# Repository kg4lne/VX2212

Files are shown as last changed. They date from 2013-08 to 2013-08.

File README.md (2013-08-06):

VX2212 EPROM Emulator
=====================

This archive contains all the CAD and firmware files necessary to build the VX2212 EPROM emulator for vintage GE Phoenix VHF/UHF commercial radios. For more information, please visit the website at http://www.rtzaudio.com/kg4lne.

This package includes all PCB CAD files in Cadsoft Eagle v6.4.0 format. The source code and firmware HEX file are included also.

The BOM files are located in the BOM subdirectory and also includes an order upload file for Digikey to preload all parts for ordering with the Digikey BOM manager. 

Hope you enjoy the project!

KG4LNE

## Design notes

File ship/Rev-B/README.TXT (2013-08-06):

These files were generated in RS274-X format (embedded apertures)
using CadSoft Eagle 5.11.0 (Win2K):

VX2212-REV-B		03/17/2011

VX2212-REV-B.PDF	Gerber Data - Fabrication drawing in Adobe PDF format
VX2212-REV-B.CMP	Gerber Data - Component side
VX2212-REV-B.SOL	Gerber Data - Solder side
VX2212-REV-B.PLC	Gerber Data - Silk screen component side
VX2212-REV-B.PLS	Gerber Data - Silk screen bottom side
VX2212-REV-B.STC	Gerber Data - Solder stop mask component side
VX2212-REV-B.STS	Gerber Data - Solder stop mask solder side
VX2212-REV-B.DRL	Drill rack file
VX2212-REV-B.DRI	Drill info file
VX2212-REV-B.DRD	Drill data for NC drill station
VX2212-REV-B.GPI	Gerber photoplotter info file

NOTE: ALL LAYERS GENERATED WITH MIRRORING OFF!

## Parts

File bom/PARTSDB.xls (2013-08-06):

Mfg Part Num | Mfg Name | VID | Vendor Part Num | Description
DNP | DO NOT PLACE | (DNP) | DNP | DO NOT PLACE
CC0603KRX7R9BB104 | Yaego | DK | 311-1344-1-ND | CAP CERAMIC .1UF 50V X7R 0603
CC0603JRNPO9BN220 | Yaego | DK | 311-1062-1-ND | CAP CERAMIC 22PF 50V 0603 SMD
T491B106K016AT | Kemet | DK | T491B106K016AT | CAP TANTALUM 10UF 16V 10% SMD 3528
ERJ-3EKF47R5V | Panasonic | DK | P47.5HCT-ND | RES 47.5 OHM 1/10W 1% 0603 SMD
ERJ-3EKF1000V | Panasonic | DK | P100HCT-ND | RES 100 OHM 1/10W 1% 0603 SMD
ERJ-3EKF4750V | Panasonic | DK | P475HCT-ND | RES 475 OHM 1/10W 1% 0603 SMD
ERJ-3EKF1002V | Panasonic | DK | P10.0KHCT-ND | RES 10.0K OHM 1/10W 1% 0603 SMD
ERJ-3EKF1003V | Panasonic | DK | P100KHCT-ND | RES 100K OHM 1/10W 1% 0603 SMD
742C083470JTR | CTS Resistor Products | DK | 742C083470JPCT-ND | RES ARRAY 47 OHM 8TERM 4RES SMD
MAX3223IPWR | Texas Instruments | DK | 296-13092-1-ND | IC DRVR/RCVR MLTCH RS232 20TSSOP
ATMEGA8-16AU | Atmel Corp | DK | ATMEGA8-16AU-ND | IC AVR MCU 8K 16MHZ IND 32-TQFP
MMBT3904LT1 | Infineon Technologies | DK | MMBT3904LT1INCT-ND | TRANSISTOR SWITCHING NPN SOT-23
BAV16W-7-F | Diodes Inc | DK | BAV16W-FDICT-ND | DIODE SWITCH 75V 400MW SOD123
MBR140SFT1G | ON Semiconductor | DK | MBR140SFT1GOSCT-ND | DIODE SCHOTTKY 40V 1A SOD123FL
MMSD4148 | Fairchild Semiconductor | DK | MMSD4148CT-ND | DIODE SML SIG 100V 0.2A SOD123
LTST-C190GKT | Lite-On Inc | DK | 160-1183-1-ND | LED GREEN CLEAR 0603 SMD
MCR03EZPJ000 | Rohm Semiconductor | DK | RHM0.0GCT-ND | RES 100K OHM 1/10W 1% 0603 SMD
801-93-050-10-001000 | Mill-Max Manufacturing | DK | ED7150-ND | SIP SOCKET 50 POS STRAIGHT PCB
ECS-147.4-18-9X | ECS Inc | DK | XC1382-ND | CRYSTAL 14.7456MHZ 18PF CYLINDR
961206-6404-AR | 3M | DK | 3M9459-ND | CONN HEADER VERT DUAL 6POS GOLD
961102-6404-AR | 3M | DK | 3M9447-ND | CONN HEADER VERT SGL 2POS GOLD
969102-0000-DA | 3M | DK | 3M9580-ND | SHUNT JUMPER .1" BLACK GOLD

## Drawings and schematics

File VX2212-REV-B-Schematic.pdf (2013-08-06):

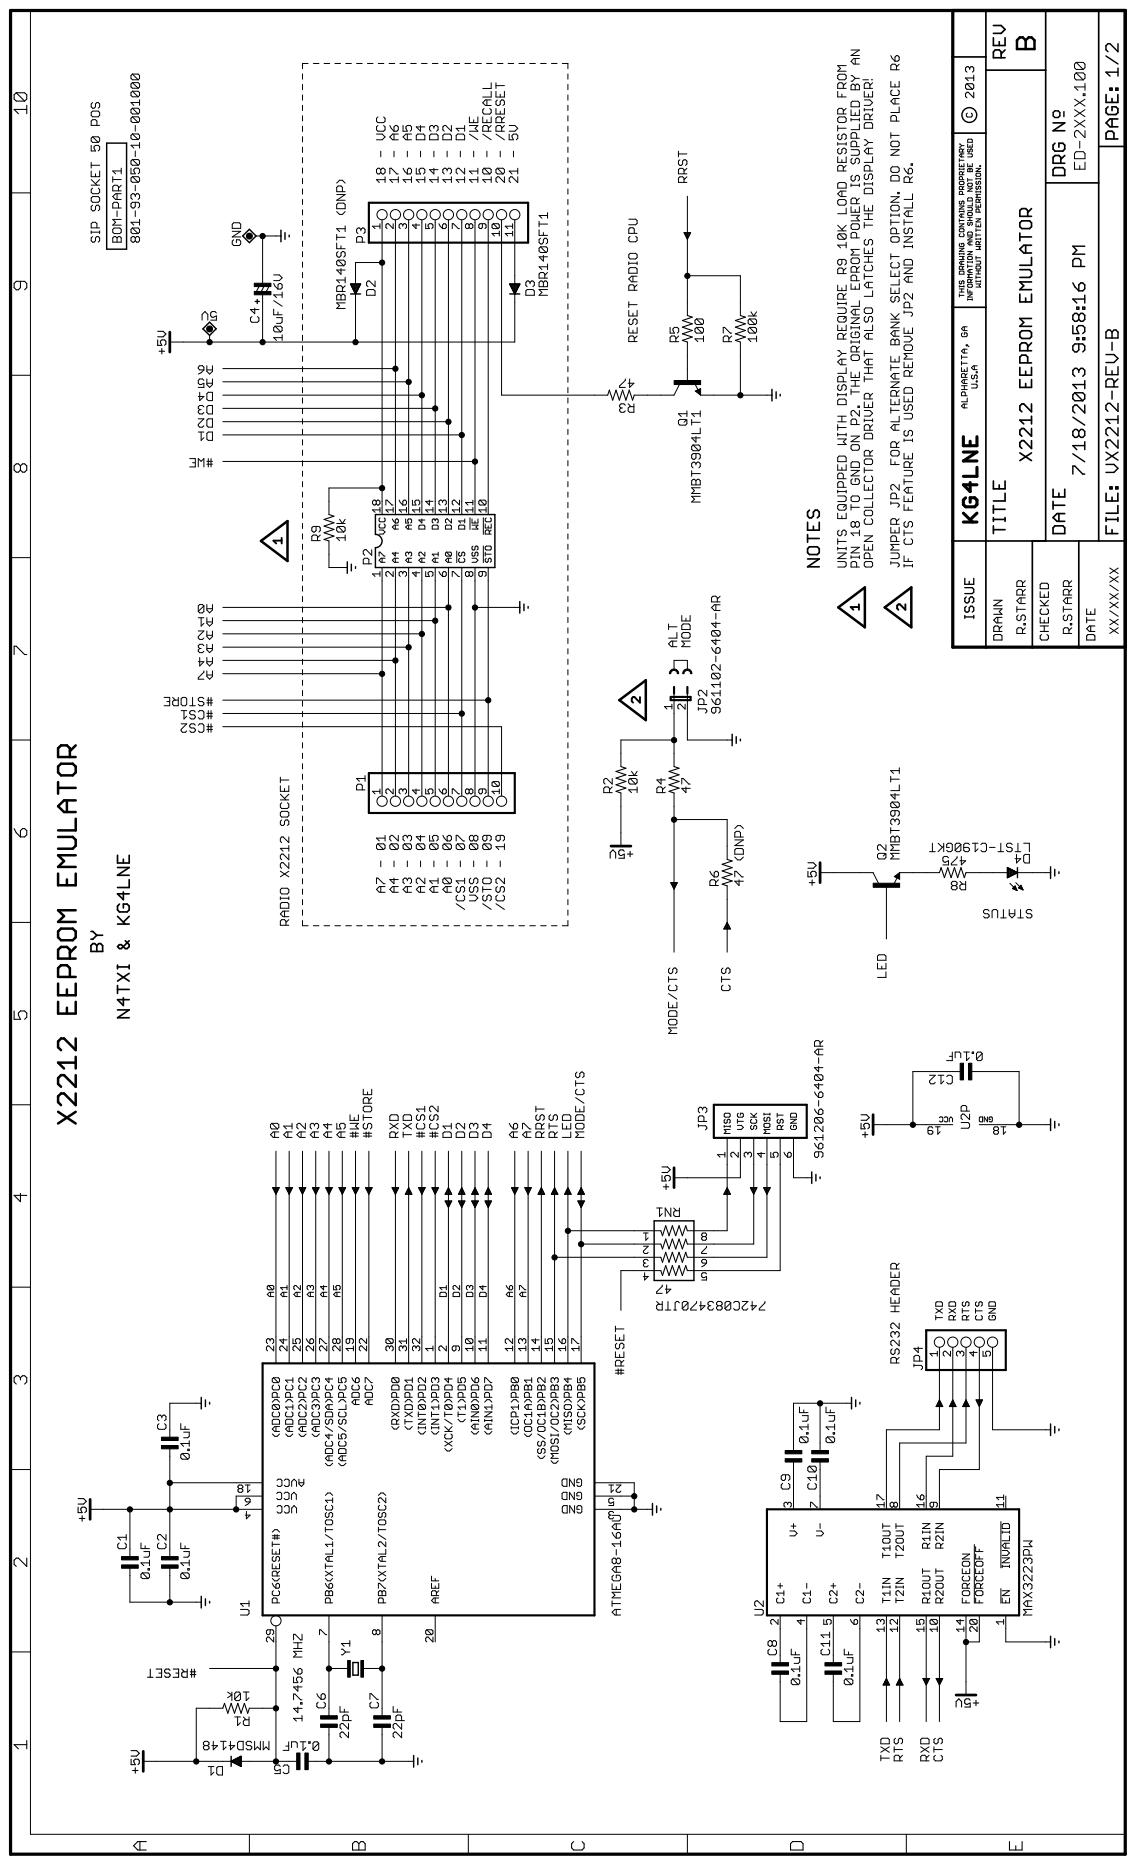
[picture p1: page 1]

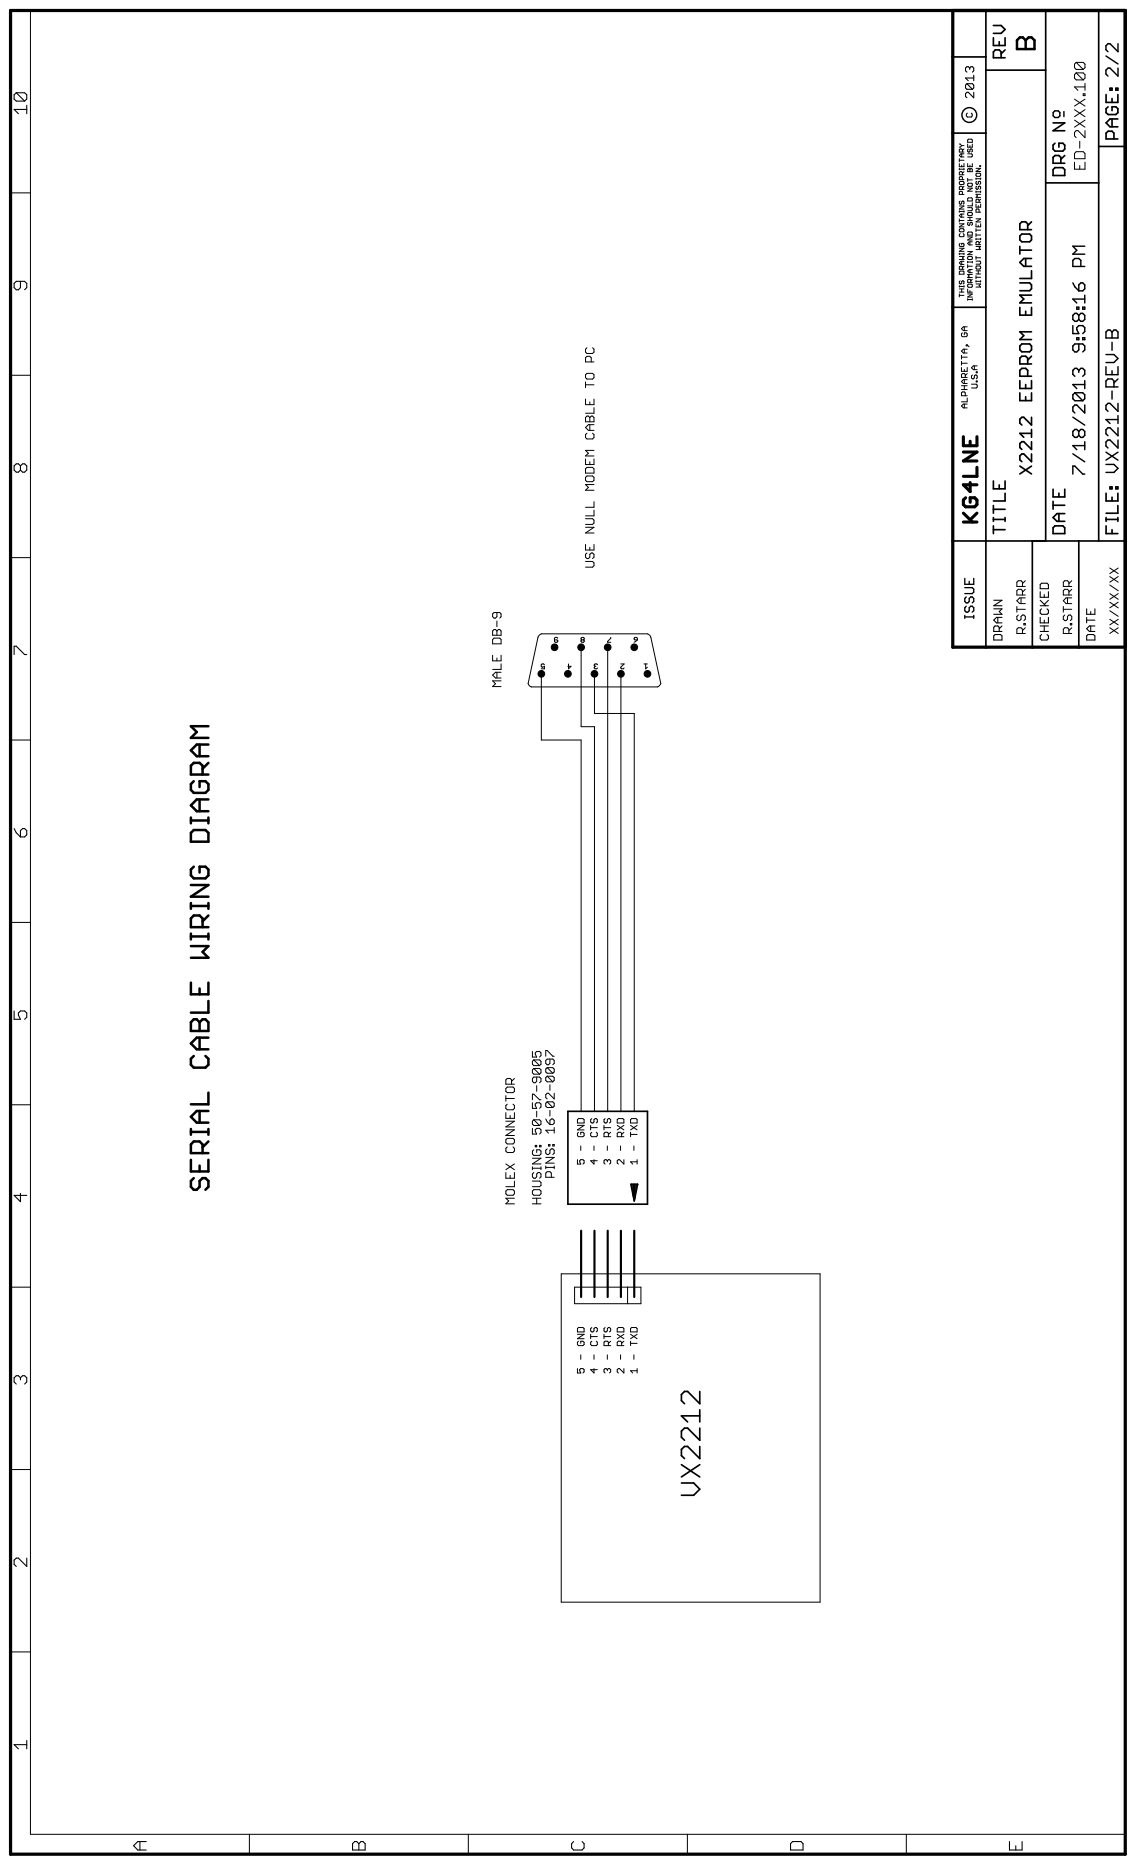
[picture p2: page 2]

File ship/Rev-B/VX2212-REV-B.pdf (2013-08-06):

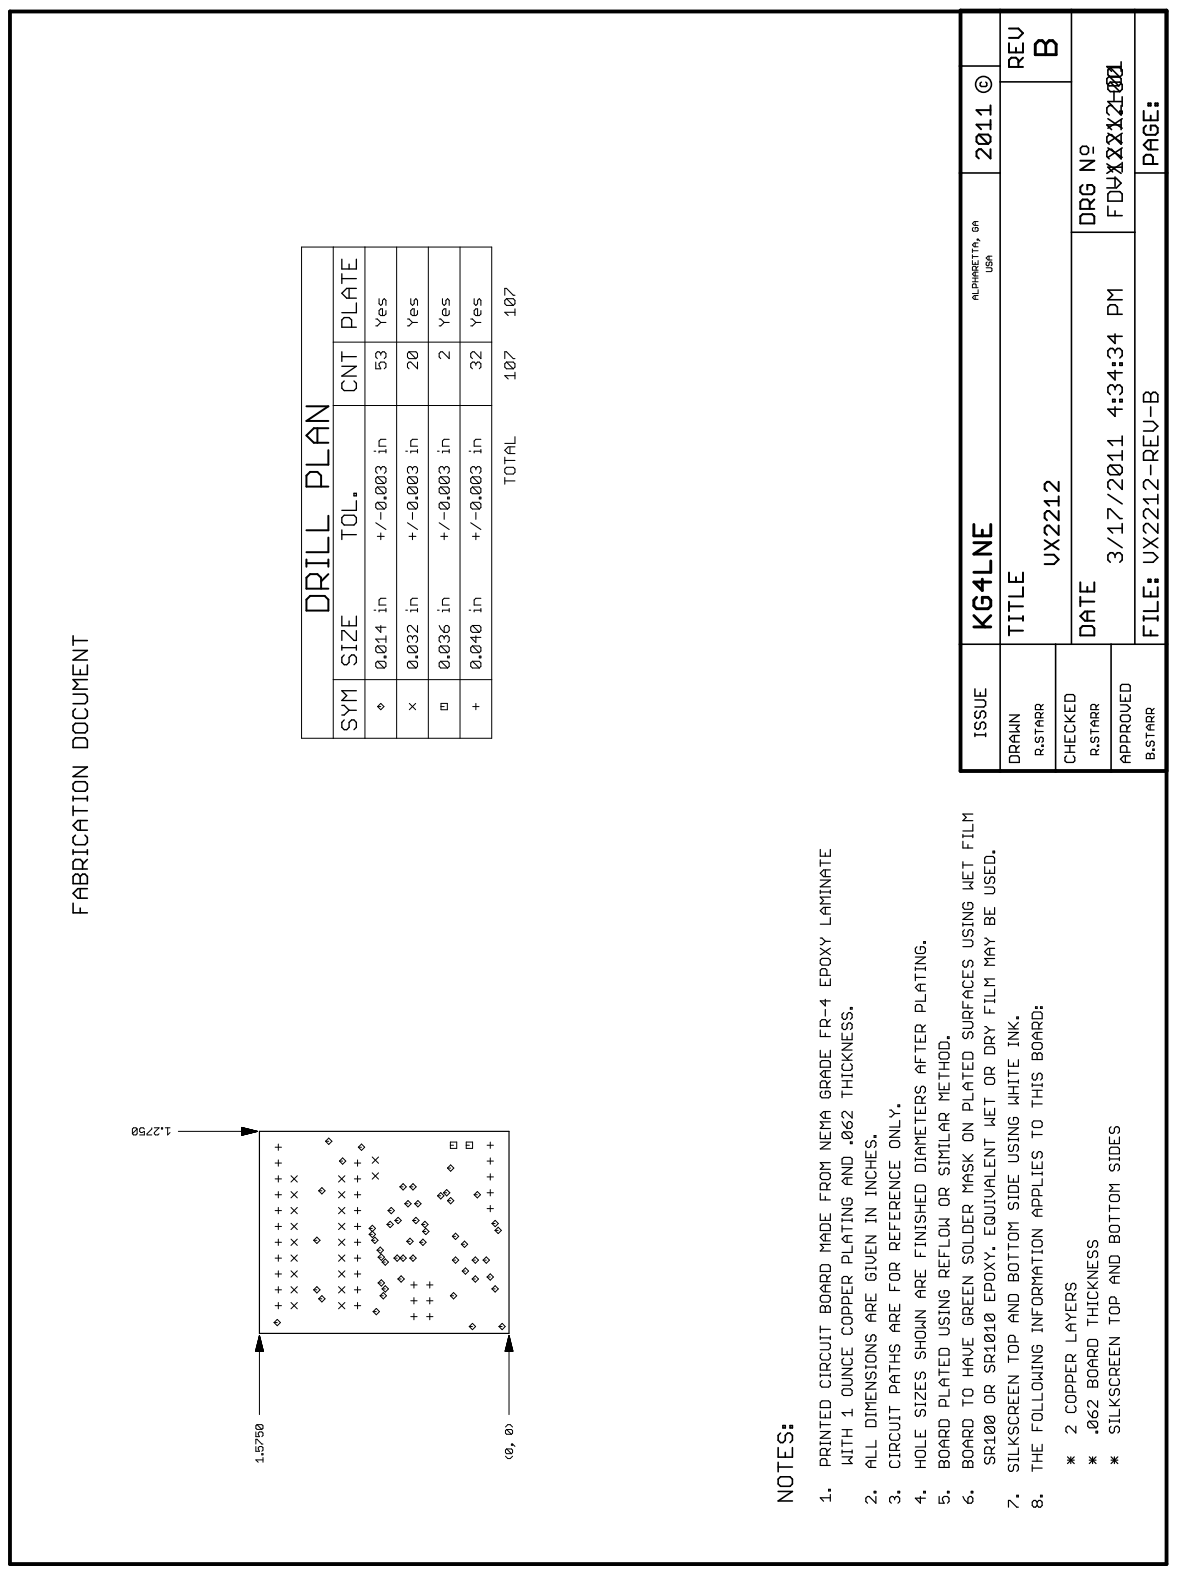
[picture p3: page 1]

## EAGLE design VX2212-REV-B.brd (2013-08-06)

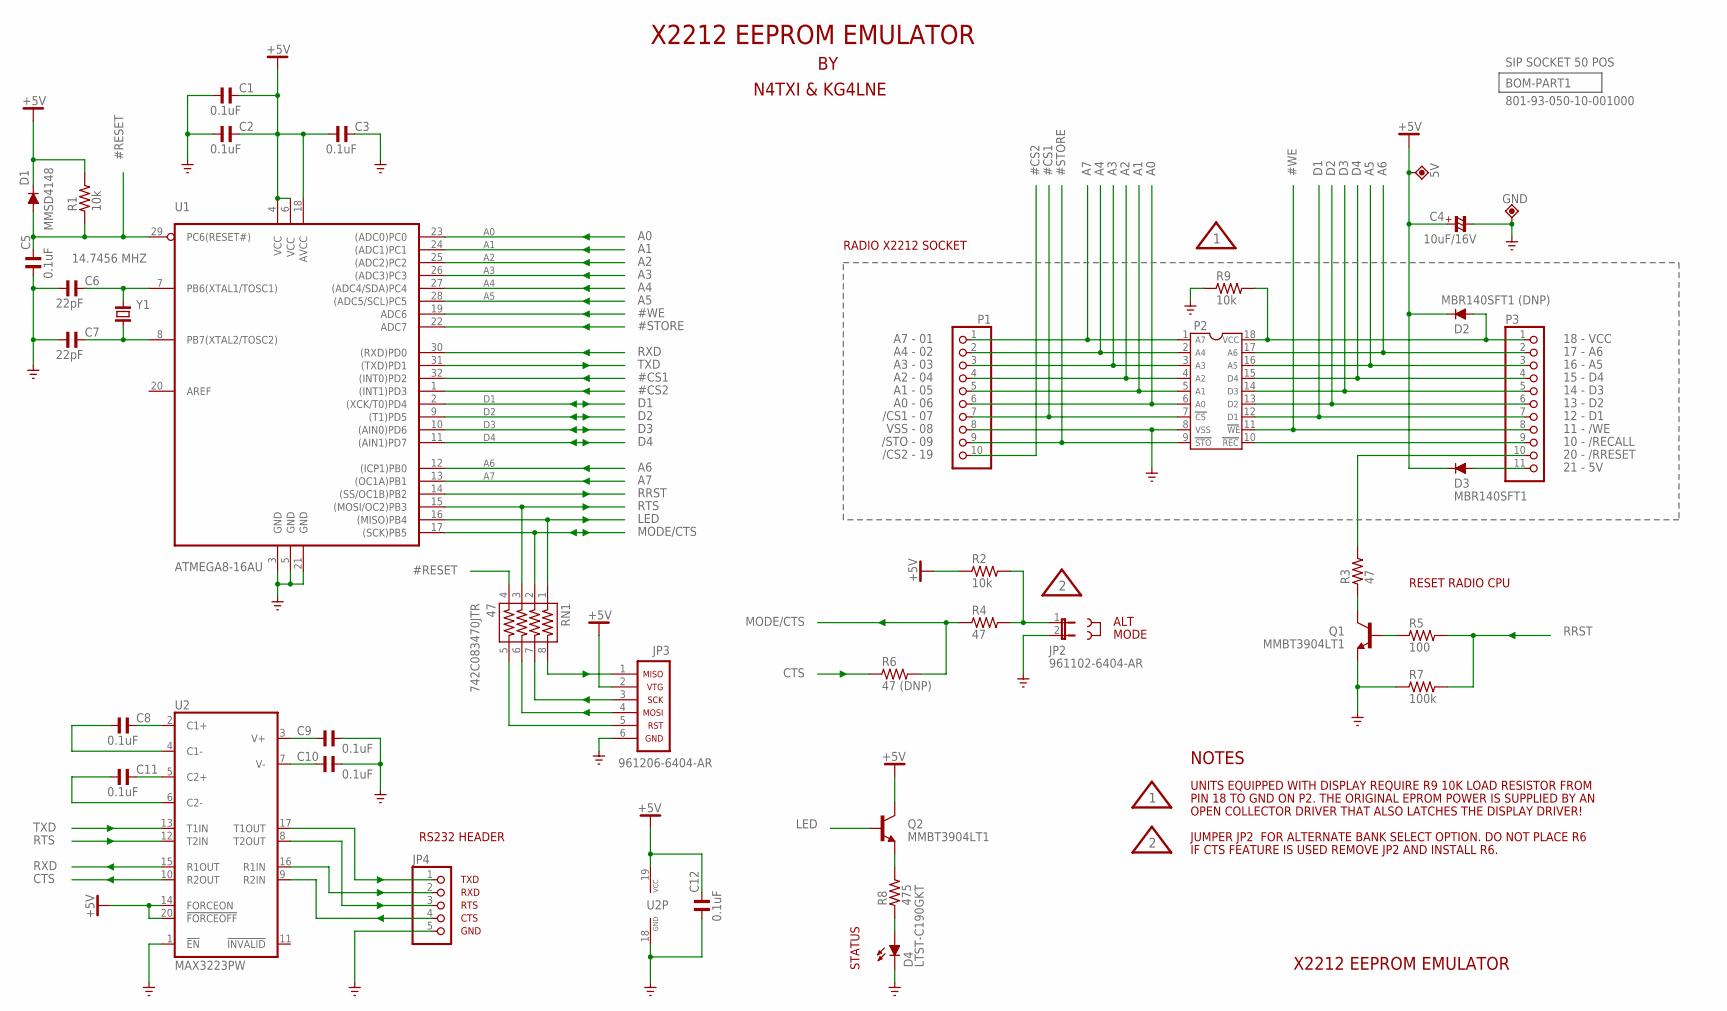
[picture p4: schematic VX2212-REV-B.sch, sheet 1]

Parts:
5V: TPP-SMD-08SN; SMD-08SN
C1, C2, C3, C5, C8, C9, C10, C11, C12: 0.1uF; C0603; PARTNO CC0603KRX7R9BB104
C4: 10uF/16V; C3528/T; PARTNO T491B106K016AT
C6, C7: 22pF; C0603; PARTNO CC0603JRNPO9BN220
D1: MMSD4148; SOD123; PARTNO MMSD4148
D2: MBR140SFT1 (DNP); SOD123LF; PARTNO DNP
D3: MBR140SFT1; SOD123LF; PARTNO MBR140SFT1G
D4: LTST-C190GKT; CHIPLED_0603; PARTNO LTST-C190GKT
GND: TPP-SMD-08SN; SMD-08SN
JP2: 961102-6404-AR; JP1; PARTNO 961102-6404-AR
JP3: 961206-6404-AR; AVR-ISP-6; PARTNO 961206-6404-AR
JP4: PINHD-1X5; 1X05
P1: PINHD-1X10; 1X10
P2: DIL18-NS
P3: PINHD-1X11; 1X11
Q1, Q2: MMBT3904LT1; SOT23-BEC; PARTNO MMBT3904LT1
R1, R2, R9: 10k; R0603; PARTNO ERJ-3EKF1002V
R3, R4: 47; R0603; PARTNO ERJ-3EKF47R5V
R5: 100; R0603; PARTNO ERJ-3EKF1000V
R6: 47 (DNP); R0603; PARTNO DNP
R7: 100k; R0603; PARTNO ERJ-3EKF1003V
R8: 475; R0603; PARTNO ERJ-3EKF4750V
RN1: 47; 742-8; PARTNO 742C083470JTR
U1: ATMEGA8-16AU; TQFP32-08; PARTNO ATMEGA8-16AU
U2: MAX3223PW; TSSOP20; PARTNO MAX3223IPWR
Y1: 14.7456 MHZ; TC39H; PARTNO ECS-147.4-18-9X

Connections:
#CS1: P1.7, P2.7, U1.32 ((INT0)PD2)
#CS2: P1.10, U1.1 ((INT1)PD3)
#RECALL: P2.10, P3.9
#RESET: C5.2, D1.A, R1.1, RN1.4, U1.29 (PC6(RESET#))
#STORE: P1.9, P2.9, U1.22 (ADC7)
#WE: P2.11, P3.8, U1.19 (ADC6)
+5V: 5V.TP, C1.2, C2.2, C3.1, C4.+, C12.2, D1.C, D2.C, D3.C, JP3.2, Q2.C, R1.2, R2.1, U1.4 (VCC), U1.6 (VCC1), U1.18 (AVCC), U2.14 (FORCEON), U2.19 (VCC), U2.20 (!FORCEOFF!)
A0: P1.6, P2.6, U1.23 ((ADC0)PC0)
A1: P1.5, P2.5, U1.24 ((ADC1)PC1)
A2: P1.4, P2.4, U1.25 ((ADC2)PC2)
A3: P1.3, P2.3, U1.26 ((ADC3)PC3)
A4: P1.2, P2.2, U1.27 ((ADC4/SDA)PC4)
A5: P2.16, P3.3, U1.28 ((ADC5/SCL)PC5)
A6: P2.17, P3.2, U1.12 ((ICP1)PB0)
A7: P1.1, P2.1, U1.13 ((OC1A)PB1)
CTS: R6.1, U2.10 (R2OUT)
D1: P2.12, P3.7, U1.2 ((XCK/T0)PD4)
D2: P2.13, P3.6, U1.9 ((T1)PD5)
D3: P2.14, P3.5, U1.10 ((AIN0)PD6)
D4: P2.15, P3.4, U1.11 ((AIN1)PD7)
GND: C1.1, C2.1, C3.2, C4.-, C5.1, C6.1, C7.1, C9.2, C10.2, C12.1, D4.C, GND.TP, JP2.2, JP3.6, JP4.5, P1.8, P2.8, Q1.E, R7.1, R9.1, U1.3 (GND), U1.5 (GND1), U1.21 (GND2), U2.1 (!EN!), U2.18 (GND)
LED: Q2.B, RN1.1, U1.16 ((MISO)PB4)
MODE/CTS: R4.1, R6.2, RN1.2, U1.17 ((SCK)PB5)
unnamed: JP4.1, U2.17 (T1OUT)
unnamed: JP3.1, RN1.8
unnamed: C11.2, U2.5 (C2+)
unnamed: D4.A, R8.1
unnamed: JP3.4, RN1.6
unnamed: JP3.3, RN1.7
unnamed: JP4.3, U2.8 (T2OUT)
unnamed: JP4.2, U2.16 (R1IN)
unnamed: C8.2, U2.2 (C1+)
unnamed: C10.1, U2.7 (V-)
unnamed: C9.1, U2.3 (V+)
unnamed: C8.1, U2.4 (C1-)
unnamed: C11.1, U2.6 (C2-)
unnamed: P3.10, R3.2
unnamed: D2.A, P2.18, P3.1, R9.2
unnamed: JP4.4, U2.9 (R2IN)
unnamed: Q2.E, R8.2
unnamed: Q1.C, R3.1
unnamed: JP2.1, R2.2, R4.2
unnamed: D3.A, P3.11
unnamed: JP3.5, RN1.5
unnamed: Q1.B, R5.1
unnamed: C7.2, U1.8 (PB7(XTAL2/TOSC2)), Y1.2
unnamed: C6.2, U1.7 (PB6(XTAL1/TOSC1)), Y1.1
RRST: R5.2, R7.2, U1.14 ((SS/OC1B)PB2)
RTS: RN1.3, U1.15 ((MOSI/OC2)PB3), U2.12 (T2IN)
RXD: U1.30 ((RXD)PD0), U2.15 (R1OUT)
TXD: U1.31 ((TXD)PD1), U2.13 (T1IN)

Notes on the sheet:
X2212 EEPROM EMULATOR
RADIO X2212 SOCKET
REC
VCC
VSS
STO
TXD
RTS
RXD
GND
RS232 HEADER
STATUS
CTS
21 - 5V
20 - /RRESET
A7 - 01
A4 - 02
A3 - 03
A2 - 04
A1 - 05
A0 - 06
/CS1 - 07
VSS - 08
/STO - 09
10 - /RECALL
11 - /WE
12 - D1
13 - D2
14 - D3
15 - D4
16 - A5
17 - A6
18 - VCC
/CS2 - 19
MODE
RESET RADIO CPU
ALT
N4TXI & KG4LNE
742C083470JTR
JUMPER JP2 FOR ALTERNATE BANK SELECT OPTION. DO NOT PLACE R6

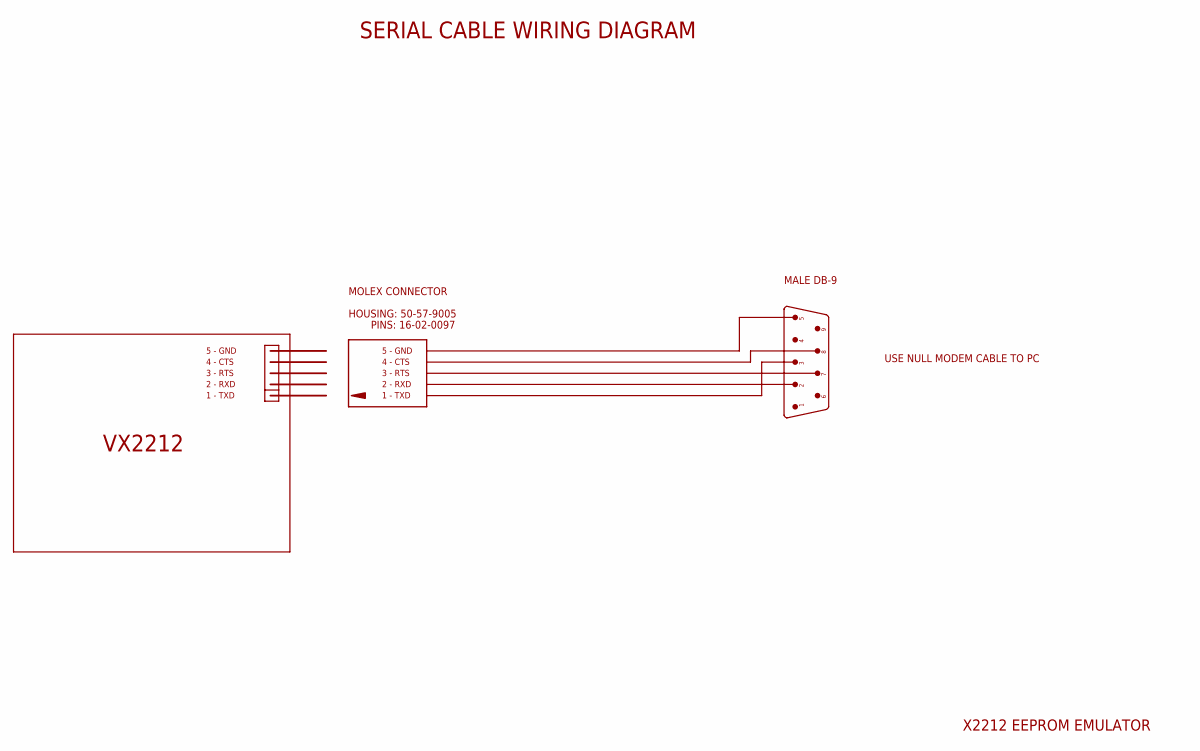
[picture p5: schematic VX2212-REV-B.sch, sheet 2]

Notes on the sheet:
1 - TXD
3 - RTS
2 - RXD
5 - GND
4 - CTS
VX2212
MOLEX CONNECTOR
HOUSING: 50-57-9005
PINS: 16-02-0097
MALE DB-9
USE NULL MODEM CABLE TO PC
SERIAL CABLE WIRING DIAGRAM
X2212 EEPROM EMULATOR

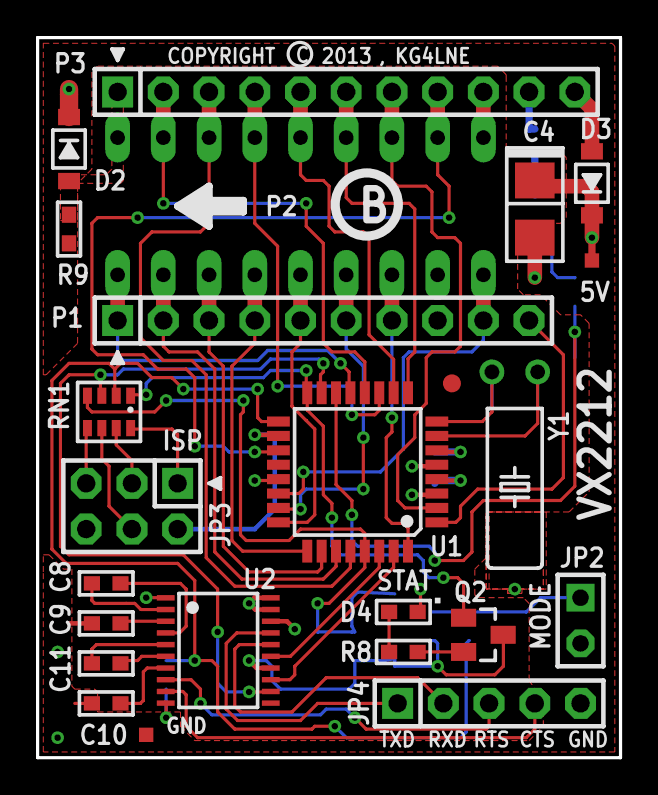
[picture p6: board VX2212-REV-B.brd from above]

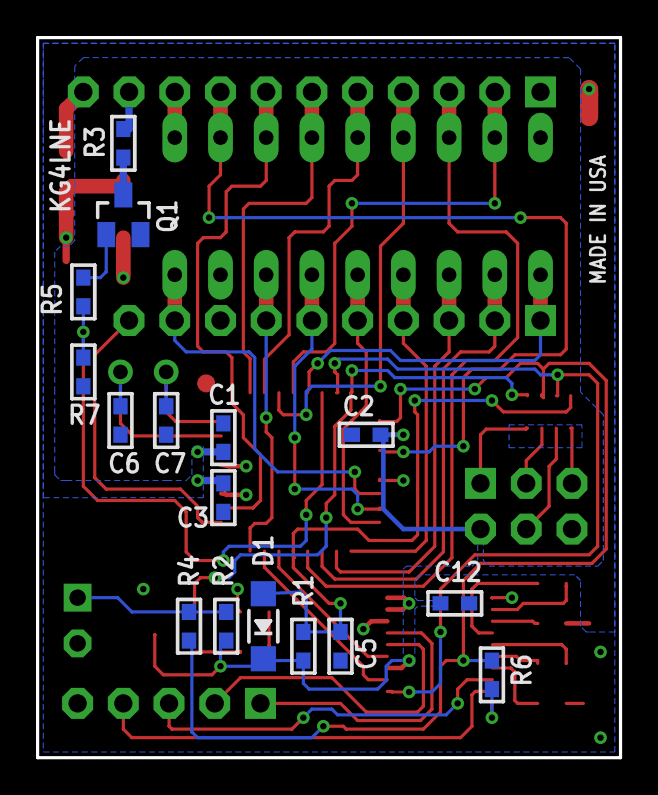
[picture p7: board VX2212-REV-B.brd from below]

Board: 2 copper layers, 32.4 x 40.0 mm, 51 parts (16 on the bottom side), 51 nets.

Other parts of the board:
$$U$1, $$U$2, $$U$3: ICON_PIN1_B
FIDUCIAL1: G10S
ICON2: ICON_ARROW-S
U$1: PCBFEAT-COPYRIGHT-032
U$5: FAB_LETTER_L
U$6: (0, 0); FAB_ARROW_LINE050
U$45: 1.5750; FAB_ARROW_LINE050
U$46: 1.2750; FAB_ARROW_LINE050
U$47: FAB_DOCFIELD_GENERIC
U$52: PCBFEAT-REV-070

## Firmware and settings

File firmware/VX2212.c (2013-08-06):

/****************************************************************************
 *
 * VX2212 Virtual X2212 EPROM Emulator - Version 1.00
 *
 * Copyright (C) 2006, Robert E Starr (KG4LNE)
 * 
 * This code is designed for use with the Atmel Mega8 processor and
 * was developed using the GCC WinAVR development tools.
 *
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
 *  1. Redistributions of source code must retain the above copyright
 *     notice, this list of conditions and the following disclaimer.
 *  2. Redistributions in binary form must reproduce the above copyright
 *     notice, this list of conditions and the following disclaimer in the
 *     documentation and/or other materials provided with the distribution.
 *  3. The name of the author may not be used to endorse or promote
 *     products derived from this software without specific prior written
 *     permission. 
 *
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
 ***************************************************************************/

#include <stdio.h>
#include <stdlib.h>
#include <string.h>
#include <inttypes.h>
#include <math.h>
#include <avr/io.h>
#include <avr/pgmspace.h>
#include <avr/interrupt.h>
//#include <avr/signal.h>
#include <avr/eeprom.h>
#include <util/delay.h>
#include <util/crc16.h>

#include "VX2212.h"
#include "async.h"

/****************************************************************************
 * Global Data
 ***************************************************************************/

uint8_t  s_cs1 = 0;             /* CS1 chip select int flag */
uint8_t  s_cs2 = 0;             /* CS2 chip select int flag */
uint8_t  s_frame[BANKSIZE];     /* serial rx frame data buffer */

/* X2212 EPROM Image Data Buffer */
uint8_t  s_bank[BANKSIZE * MAX_BANKS];

/* This table is used to mirror the data bit order to correct
 * for a hardware mistake. The 4-bit data buss order is reversed
 * from the actual data order. So, we mirror the bits in our
 * lookup table prior to storing EPROM data for speed.
 */

const uint8_t s_xbit[16] = {
    0x00,   // 00 : 0000 => 0000 (0x00)
    0x08,   // 01 : 0001 => 1000 (0x08)
    0x04,   // 02 : 0010 => 0100 (0x04)
    0x0C,   // 03 : 0011 => 1100 (0x0C)
    0x02,   // 04 : 0100 => 0010 (0x02)
    0x0A,   // 05 : 0101 => 1010 (0x0A)
    0x06,   // 06 : 0110 => 0110 (0x06)
    0x0E,   // 07 : 0111 => 1110 (0x0E)
    0x01,   // 08 : 1000 => 0001 (0x01)
    0x09,   // 09 : 1001 => 1001 (0x09)
    0x05,   // 10 : 1010 => 0101 (0x05)
    0x0D,   // 11 : 1011 => 1101 (0x0D)
    0x03,   // 12 : 1100 => 0011 (0x03)
    0x0B,   // 13 : 1101 => 1011 (0x0B)
    0x07,   // 14 : 1110 => 0111 (0x07)
    0x0F    // 15 : 1111 => 1111 (0x0F)
};

/* Do not remove! */
const char copyright[] PROGMEM = {
    "VX2212 v1.00, Copyright (C) 2007-2009, KG4LNE"
};


/****************************************************************************
 * MAIN - Program entry at startup.
 ***************************************************************************/

int main(void)
{
    int      c;
    int      stat;
    uint8_t  mode;
    uint32_t count = 0;
    register uint8_t addr;
    register uint16_t bankoff;

    /* Setup default I/O pins and assignments */
    init_io();

    /* Initialize the USART serial port driver */
    asi_init();

    asi_putc('<');

    /* Blink the LED 1 or 2 times at power up to 
     * indicate the MODE jumper JP2 select state.
     */

    mode = (PINB & _BV(B_MODE)) ? 0 : 1;
    
    blink_led(mode+1, 150);

    /* Read EPROM image into RAM */
    eeprom_read_block(s_bank, 0, BANKSIZE * MAX_BANKS);

    /* Force a radio CPU reset */
    reset_radio();

    /* Final device init, startup interrupts */
    start_ints();

    /*
     * Enter the main X2212 EPROM emulation loop.
     */

    bankoff = (mode) ? BANKSIZE : 0;

    for (;;)
    {
        /* TEST FOR /CS ACTIVE (low) */

        //if (s_cs1)
        if ((PIND & _BV(B_CS)) == 0)
        {
            /* EPROM READ /CS ACTIVE STATE */

            PORTB |= _BV(B_LED);

            /* read the address data lines */
            addr = (PINC & 0x3F) + (PINB << 6);

            /* output the data to the buss */
            PORTD = s_bank[addr+bankoff] << 4;
            //PORTD = s_bank[addr] << 4;
        }
        else
        {
            /* LED blink state counter */
            if (++count == 250000)
            {
                count = 0;
                PORTB ^= _BV(B_LED);
            }

            /* RS-232 SERIAL PORT PROCESSING */

            /* Any character received? */
            if ((c = asi_getc()) != '.')
                continue;

            /* LED off while we read from serial */
            PORTB &= ~(_BV(B_LED));

            /* Got a period, echo back STX to begin packet rx */
            asi_putc(STX);

            /* Attempt to read a data/command packet */

            do {

                /* attempt to read a packet */
                stat = rx_packet(); 

            } while (stat == 0);
        }
    }

    return 0;
}

/* Attempt to receive a serial command packet from the host (GE-Flash).
 * If we get a valid packet then decode the command and process it.
 */

int rx_packet(void)
{
    int         c;
    int         stat = -1;
    uint8_t     flgcmd;
    uint8_t     banknum;
    uint16_t    lsb;
    uint16_t    msb;
    uint16_t    len;
    uint16_t    i;
    uint16_t    crc;
    uint16_t    crc_packet;

    crc = 0;

    /* Read the SOH first (wait up to 5 seconds) */
    if ((c = asi_tgetc(500)) == -1)
        return 1;
    if (c != SOH)
        return 2;

    // Read 'len_msb' byte
    if ((c = asi_tgetc(100)) == -1)
        return 3;
    crc = _crc_xmodem_update(crc, c);
    msb = (uint16_t)c;

    // Read 'len_lsb' byte
    if ((c = asi_tgetc(100)) == -1)
        return 4;
    crc = _crc_xmodem_update(crc, c);
    lsb = (uint16_t)c;
    len = (msb << 8) | lsb;

    // Read 'flgs/cmd' byte
    if ((c = asi_tgetc(100)) == -1)
        return 5;
    crc = _crc_xmodem_update(crc, c);
    flgcmd = (uint16_t)c;

    // Read 'bank#' byte state
    if ((c = asi_tgetc(100)) == -1)
        return 6;
    crc = _crc_xmodem_update(crc, c);
    banknum = (uint16_t)c & 0x1;

    // frame length validation
    if (len > 256)
        return 7;

    // Read any data for length specified
    for (i=0; i < len; i++)
    {
        // Read a byte of data from the stream
        if ((c = asi_tgetc(100)) == -1)
            return 8;
        // Update CRC with the data byte
        crc = _crc_xmodem_update(crc, c);
        // Store it in the rx frame buffer
        s_frame[i] = c;
    }

    /* final CRC calculation */
    crc = _crc_xmodem_update(_crc_xmodem_update(crc,0),0);

    // Read CRC MSB byte
    if ((msb = asi_tgetc(100)) == -1)
        return 9;

    if ((lsb = asi_tgetc(100)) == -1)
        return 10;

    // Get the packet CRC value
    crc_packet = (msb << 8) | lsb;

    // Check if the CRC's match
    if (crc != crc_packet)
    {
        asi_putc(NAK);
        asi_putc(msb);
        asi_putc(lsb);
        // We return 0 to indicate continue reading
        // another packet after a NAK. 
        return 0;
    }

    /* VALID FRAME RECEIVED - DECODE THE COMMAND */

    stat = 0;

    switch(flgcmd & 0x0F)
    {
        case VXCMD_PING:
            break;

        case VXCMD_WRITE_BANK:
            /* Patch downloaded data to correct for mirrored data lines */
            for (i=0; i < BANKSIZE; i++)
                s_frame[i] = s_xbit[s_frame[i] & 0x0f];

            /* Copy from temp rx buffer to active emulation buffer */
            memcpy(&s_bank[banknum * BANKSIZE], s_frame, BANKSIZE);

            /* Test to see if this is the last packet or MORE are to follow */
            if (flgcmd & F_VXCMD_MORE)
            {
                /* More packets will follow this one.. */
                /* Tell host we stored the bank */
                asi_putc(ACK);
                asi_putc(msb);
                asi_putc(lsb);
            }
            else
            {
                /* Save the new data to our EPROM */
                eeprom_write_block(s_bank, 0, BANKSIZE * MAX_BANKS);
                /* Tell host we stored the bank */
                asi_putc(ACK);
                asi_putc(msb);
                asi_putc(lsb);
                /* Blink the LED 2 times upon completion */
                blink_led(2, 75);
                /* Reset the radio cpu */
                reset_radio();
                /* exit read packet loop */
                stat = -1;
            }
            break;

        case VXCMD_READ_BANK:
            /* Copy from active emulation buffer to tx buffer */
            memcpy(s_frame, &s_bank[banknum * BANKSIZE], BANKSIZE);

            /* Un-mirror/copy data bits */
            for (i=0; i < BANKSIZE; i++)
                s_frame[i] = s_xbit[s_frame[i]];

            /* Send the packet */
            tx_packet(VXCMD_READ_BANK, banknum, s_frame, BANKSIZE);
            break;

        case VXCMD_GET_ACTIVE_BANK:
            break;

        case VXCMD_SET_ACTIVE_BANK:
            break;

        default:
            break;
    }

    return stat;
}


int tx_packet(uint8_t flgcmd, uint8_t bank, uint8_t* data, uint16_t datasize)
{
    int      i;
    uint16_t lsb;
    uint16_t msb;
    uint16_t crc = 0;

    /* Send the SOH first (0) */
    asi_putc(SOH);

    /* Send the length MSB/LSB bytes */
    msb = (uint16_t)datasize >> 4;;
    lsb = (uint16_t)datasize & 0xff;

    /* Send CRC MSB byte (1) */
    crc = _crc_xmodem_update(crc, msb);
    asi_putc(msb);

    /* Send CRC LSB byte (2) */
    crc = _crc_xmodem_update(crc, lsb);
    asi_putc(lsb);

    /* Send the FLG/CMD byte (3) */
    crc = _crc_xmodem_update(flgcmd, lsb);
    asi_putc(flgcmd);

    /* Send the BANK# byte (4) */
    crc = _crc_xmodem_update(flgcmd, bank);
    asi_putc(bank);

    /* Send any DATA payload */
    if (data && datasize)
    {
        for (i=0; i < datasize; i++)
        {
            crc = _crc_xmodem_update(crc, data[i]);
            asi_putc(data[i]);
        }
    }

    /* Send the CRC MSB */
    asi_putc((int)(crc >> 4) & 0xff);

    /* Send the CRC LSB */
    asi_putc((int)crc & 0xff);

    return 0;
}

/* Issue a reset pulse to the radio CPU */

void reset_radio(void)
{
    PORTB |= _BV(B_RRST);
    /* ~100us */
    _delay_loop_2(5*100);
    PORTB &= ~(_BV(B_RRST));
    /* ~100us */
    //_delay_loop_2(5*100);
}

/* Blink the LED for count and rate duration */

void blink_led(uint16_t count, uint16_t rate)
{
    uint16_t i;
    /* Blink the n times at ms delay rate */
    for (i=0; i < count; i++)
    {
        PORTB |= _BV(B_LED);
        delay_ms(rate);
        PORTB &= ~(_BV(B_LED));
        delay_ms(rate);
    }
}

/****************************************************************************
 * Initialize the VX2212 I/O ports
 ***************************************************************************/

void init_io(void)
{
    /* PORT-C
     *
     * PCO  = A0        (in)
     * PC1  = A1        (in)
     * PC2  = A2        (in)
     * PC3  = A3        (in)
     * PC4  = A4        (in)
     * PC5  = A5        (in)
     * ADC6 = /WE       (in)
     * ADC7 = /STORE    (in)
     */

    /* all pins low */
    PORTC = 0x00;
    /* all pins are input */
    DDRC  = 0x00;

    /* PORT-D
     *
     * PDO  = RXD       (in)
     * PD1  = TXD       (out)
     * PD2  = /CS       (in)
     * PD3  = /RECALL   (in)
     * PD4  = D4        (in/out)
     * PD5  = D3        (in/out)
     * PD6  = D2        (in/out)
     * PD7  = D1        (in/out)
     */

    /* all pins low */
    PORTD = 0x00;
    /* all pins are input for now */
    DDRD  = 0x00;
    /* PD1=output, PD4-PD7=output */
    DDRD  = _BV(PD1) | _BV(PD4) | _BV(PD5) | _BV(PD6) | _BV(PD7);

    /* PORT-B
     *
     * PBO  = A6        (in)
     * PB1  = A7        (in)
     * PB2  = RRST      (out)
     * PB3  = RTS       (out)
     * PB4  = LED       (out)
     * PB5  = MODE      (in)
     */

    /* all pins low */
    PORTB = 0x00;
    /* all pins are input for now */
    DDRB  = 0x00;
    /* PB2-PB4=output, PB0, PB1 & PB5 are input */
    DDRB  = _BV(PB2) | _BV(PB3) | _BV(PB4);
}

/* Here we startup any interrupts or devices needed */

void start_ints(void)
{
    cli();

#if 0
    uint16_t cmatch;
    cmatch = (uint16_t)((F_CPU / TICK_RATE_HZ) / 1024UL);
    /* no compare/pwm/capture mode */
    TCCR1A = 0;
    /* setup this timer's prescaler 1024 */
    TCCR1B = 128;   //1024;
    /* Setup the timer starting value */
    TCNT1L = (uint8_t)cmatch;
    TCNT1H = (uint8_t)(cmatch >> 8);
    /* enable the timer/counter1 overflow interrupt in the T/C int mask register */
    timer_enable_int(_BV(TOIE1));
#endif

	// Enable the external interrupt for INT0/PD2
    MCUCR   = (1<<ISC00);       // Set interrupt on fall and on rise
    GICR	= (1<<INT0);		// Enable interrupt for interrupt0

    sei();
}

/****************************************************************************
 * General Purpose Functions
 ***************************************************************************/

void delay_ms(uint16_t ms)
{
    uint16_t d;

    for (d=0; d < ms; d++) {
        /* 16-bit count - 4 cycles/loop */
        _delay_loop_2((uint16_t)(F_CPU / 4000UL));
    }
}

/* ~21 cycles per microsecond */
#define CYCLES_PER_US       ((F_CPU+500000UL)/1000000UL)

void delay_us(uint16_t us) 
{
    uint16_t dcnt;
    dcnt = (us+3) / 3 * CYCLES_PER_US;
    /* 16-bit count - 4 cycles/loop */
    _delay_loop_2(dcnt / 4);
}

/****************************************************************************
 * Change PORT direction based on condition of INT0 Pin (/CS).
 ***************************************************************************/

SIGNAL(SIG_INTERRUPT0)
{
    if (PIND & 0x04)        // Chip select line high (not enabled)
    {
        DDRD &= ~0xF0;      // Tri-state the outputs!
        s_cs1 = 0;        // chip select CS1/ inactive
    }
    else                    // Chip select line low (enabled)
    {
        DDRD |= 0xF0;       // Drive the outputs
        s_cs1 = 1;        // chip select CS1/ active
    }
}

#if 0
SIGNAL(SIG_INTERRUPT1)
{
    if (PIND & 0x04)        // Chip select line high (not enabled)
    {
        DDRD &= ~0xF0;      // Tri-state the outputs!
        s_cs2 = 0;        // chip select CS1/ inactive
    }
    else                    // Chip select line low (enabled)
    {
        DDRD |= 0xF0;       // Drive the outputs
        s_cs2 = 1;       // chip select CS1/ active
    }
}
#endif

/****************************************************************************
 *
 ***************************************************************************/

#define TICK_RATE_HZ    60UL

SIGNAL(SIG_OVERFLOW0)
{
    uint16_t cmatch;

    cmatch = (uint16_t)((F_CPU / TICK_RATE_HZ) / 1024UL);

    /* Setup the timer starting value */
    TCNT1L = (uint8_t)cmatch;
    TCNT1H = (uint8_t)(cmatch >> 8);

//    PORTB |= _BV(B_LED);
}

/*
 // controller ATmega8
> CLI(); //disable all interrupts
>
> // desired value: 1Sec
>
>  TCNT1  = 0xF0BE; //setup
> //start Timer (prescale:1024 input from internal clk)
> TCCR1B = 0x05;
>
> //timer interrupt sources (TOIE1: Timer/Counter0 Overflow Interrupt
> Enable)
> TIMSK  = 0x04;
>
> SEI(); //re-enable interrupts
>
> The interrupt:
>
> #pragma interrupt_handler timer1_ovf_isr:7
> void timer1_ovf_isr(void)
> {
>  WDR();
>  TCNT1  = 0xF0BE; //reload counter low value
> }
>
*/

/* End-Of-File */

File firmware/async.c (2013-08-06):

/****************************************************************************
 *
 * Micro-RC Repeater Controller
 *
 * Copyright (C) 2005-2006, Robert E. Starr, Jr. (KG4LNE)
 *
 * Email: kg4lne@mindspring.com
 *
 * Web: http://www.rtzaudio.com/kg4lne
 *
 * This code is designed for use with the Micro-RC repeater controller 
 * and Atmel Mega128 processor. All code was developed using the GCC WinAVR
 * development tools.
 *
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
 *  1. This source code may not be used, modified, adapted or integrated 
 *     into any commercial or business product without specific written 
 *     permission from the author.
 *
 *  2. This source code and all portions withing is designed for use with
 *     the Micro-RC repeater controller. Use of this code in source or binary
 *     form on repeater controller hardware other than the Micro-RC is
 *     strictly forbidden.
 *
 *  3. Redistributions of source code must retain the above copyright
 *     notice, this list of conditions and the following disclaimer.
 *
 *  4. Redistributions in binary form must reproduce the above copyright
 *     notice, this list of conditions and the following disclaimer in the
 *     documentation and/or other materials provided with the distribution.
 *
 *  5. The name of the author may not be used to endorse or promote
 *     products derived from this software without specific prior written
 *     permission. 
 *
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
 ***************************************************************************/

#include <stdio.h>
#include <stdlib.h>
#include <string.h>
#include <inttypes.h>
#include <avr/io.h>
#include <avr/interrupt.h>

#include "async.h"

extern void delay_ms(uint16_t ms);

#define SLEEP_MS(n)     ( delay_ms(n) )

/* Declare our static serial ring buffers and 
 * buffer management data items.
 */

static ASYNC async;

/****************************************************************************
 * USART INITIALIZATION
 ***************************************************************************/

void asi_init(void) 
{
#if defined(__AVR_ATmega8__)
    /* Set baud rate */
    UBRRH = 0;
    UBRRL = (uint8_t)((F_CPU / (16UL * BAUD_RATE)) - 1UL);
    /* Enable receiver, transmitter and rx interrupts */
    UCSRB = (1<<RXCIE)|(1<<RXEN)|(1<<TXEN);
    // Set frame format to 8 data bits, no parity, and 1stop bit
    UCSRC = (1<<URSEL)|(3<<UCSZ0);
#else
    /* Set baud rate */
    UBRR0L = (uint8_t)((F_CPU / (16UL * BAUD_RATE)) - 1UL);
    UBRR0H = 0;
    /* Enable receiver and transmitter */
    UCSR0B = (1<<RXEN) | (1<<TXEN) | (1<<TXCIE);
    /* Set frame format: 8 data bits, no parity, 1 stop bit */
    //UCSRC  = (1<<URSEL)|(3<<UCSZ0);
    UCSR0C = (3<<UCSZ0);
    /* Enable the RTS and CTS outputs */
	//PORTE |= _BV(COM_RTS) | _BV(COM_CTS);
#endif

    /* Setup async ring buffer pointers */
    async.rx.head  = 0;     /* tx queue head index */
    async.rx.tail  = 0;     /* tx queue tail index */
    async.rx.count = 0;     /* tx queue size       */

    async.tx.head  = 0;     /* tx queue head index */
    async.tx.tail  = 0;     /* tx queue tail index */
    async.tx.count = 0;     /* tx queue size       */

    /* hook to stdlib printf() functions etc */
	//fdevopen(asi_putc, NULL, 0);
}

/****************************************************************************
 * READ functions
 ***************************************************************************/

/*
 * Name:        ASI_GETC - Get character from receive queue.
 *
 * Synopsis:    int asi_getc(port)
 *              int port;   - port number  (0-16)
 *
 * Description: Gets a character from the receive the queue.
 *
 * Return:      -1 if error occured.
 */

int asi_getc(void)
{
    int     c = -1;
    size_t  head;

    if (async.rx.head != async.rx.tail)
    {
        head = async.rx.head;                       /* get head pointer  */

        c = async.rx.buf[head++];                   /* get char in buff  */

        c &= 0xff;

        --(async.rx.count);                         /* dec buffer count  */

        async.rx.head = (head >= ASYNC_RX_BUFSIZE) ? 0 : head;
    }

    return c;
}

/*
 * Name:        ASI_READ - Read 'n' characters from comm port.
 *
 * Synopsis:    int asi_read(port, buf, buflen)
 *              int port;   - port number
 *              char *buf;  - pointer to data buffer
 *              int buflen; - data buffer length
 *
 * Description: Reads 'n' characters to the comm port and returns
 *              the number of bytes actually read. The number
 *              of bytes read may not equal the amount requested.
 *
 * Return:      Number of characters actually read.
 */

int asi_read(char *buf, size_t buflen)
{
    char *p = buf;
    int  i;
    int  ch;
    int  cnt = 0;

    for (i=0; i < buflen; i++, p++)
    {
        if ((ch = asi_getc()) == -1)
            break;

        *p = (char)ch;

        ++cnt;
    }

    return cnt;

}

/*
 * Name:        ASI_TGETC - Get character from receive queue.
 *
 * Synopsis:    int asi_tgetc(port, timeout)
 *              int port;       - port number  (0-16)
 *              int timeout;    - timeout value in 10ms counts (0=none)
 *
 * Description: Gets a character from the receive the queue.
 *
 * Return:      -1 if error occured.
 */

int asi_tgetc(int timeout)
{
    int c;
    int i;

    if (!timeout)                       /* timeout specified?   */
        return asi_getc();              /* no, just return it   */

    for (i=0; i < timeout; i++)
    {
        if ((c = asi_getc()) != -1)     /* any character found? */
            return c;                   /* yes, return it       */

        SLEEP_MS(10);
    }

    return -1;
}


/*
 * Name:        ASI_TGETS - Read a string from the modem.
 *
 * Synopsis:    int asi_gets(port, timeout, buf)
 *              int port;   - serial port number
 *              int timeout;    - read timeout in seconds
 *              char buf[]; - read string buffer {0:63}
 *
 * Description: This function reads a string up to 63 characters 
 *              from the modem with timeout.
 *
 * Returns:     Number of characters sent to the modem.
 */

int asi_tgets(int timeout, char buf[])
{
    int c;
    int i;

    buf[0] = '\0';

    for (i=0; i < 63; i++)
    {
        if ((c = asi_tgetc(timeout)) == -1)
            return(0);

        if (c == '\r') 
            continue;

        if (c == '\n')
        {
            buf[i] = '\0';
            break;
        }

        buf[i] = (char)c;
        buf[i+1] = '\0';
    }

    return i;
}

/****************************************************************************
 * WRITE functions
 ***************************************************************************/

/*
 * Name:        ASI_PUTC - Put character in transmit queue.
 *
 * Synopsis:    int asi_putc(port, c)
 *              int port;   - port number
 *              int c;      - character to place in buffer
 *
 * Description: Places a character in the transmit queue.
 *
 * Return:      -1 if error occured.
 */
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

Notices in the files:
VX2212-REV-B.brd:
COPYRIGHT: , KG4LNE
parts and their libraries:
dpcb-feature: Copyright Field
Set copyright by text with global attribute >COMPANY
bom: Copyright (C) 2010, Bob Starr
